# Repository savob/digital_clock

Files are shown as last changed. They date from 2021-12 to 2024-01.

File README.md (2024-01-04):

# Digital Clock
A hardware only digital clock project, my first embedded project without a single microcontroller involved!

Designed in a modular system to allow easy reconfiguration and expirimentation with each module. There are three modules:
1. Display module - These each carry a pair of LED seven segment character displays, their drivers, and a counter for each digit
2. Reset logic module - These recieve the data for a pair of digits and routes it through logic gates to determine if a digit needs to be reset (e.g. at 10)
3. Signal generator module - This generates the base 1 Hz signal used by the clock and provides the power for all other modules

### Small Notice
In the original designs of the reset modules I either forgot or naively didn't bother to include decoupling capacitors for the ICs. This caused the system to be incredibly suseptible to any sort of electrostatic discharge in the surrendings and throwing off the time.

This has been addressed in the newer version.

## Display Module
The main modules present; serve to house and drive two displays each as well as the counter for each digit. The digits are all standard LED seven-segment character displays and can be either common anode (CA) or common cathode (CC) types. The board can accomadate either by switching the driver chip used and a solder jumper accordingly. The left digit is referred to as the "primary" and the right one as "secondary".

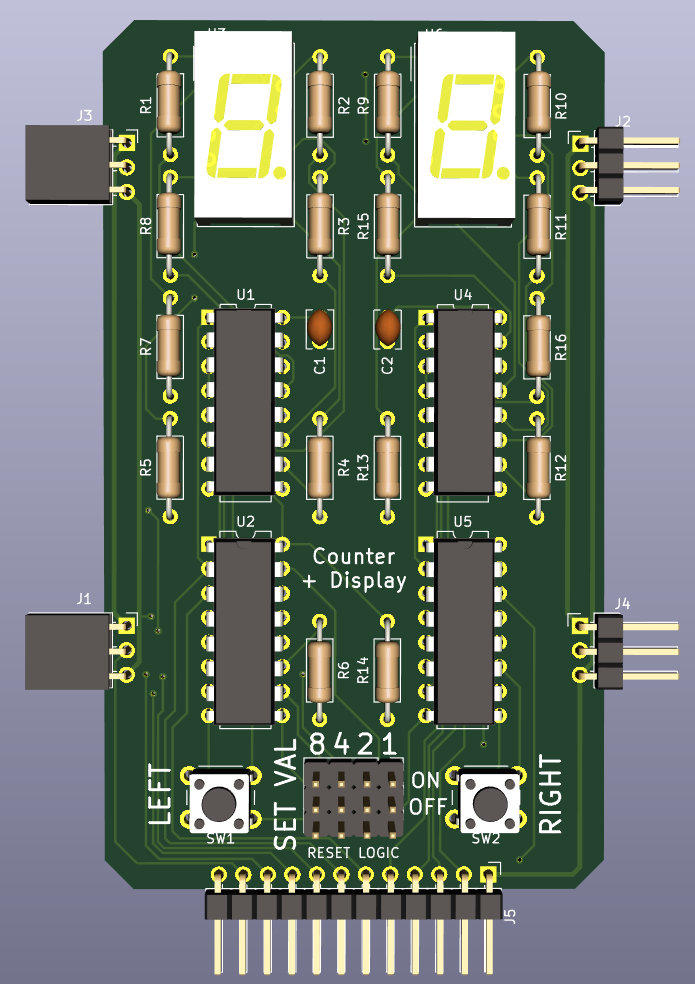
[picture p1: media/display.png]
3D render of the display board


The counters serve to store the value for each digit and increment it when they recieve a clock signal. When a digit "turns over" (returns to zero, resets) this is also used as the signal to increment the next digit up. The result is the count (time) is propagated right to left through the system like a normal clock. The logic to reset digits is not housed on these boards themselves, instead the signals for the value of each couter and their reset signal are routed to the bottom to be handled by the logic modules. 

## Reset Logic Module
This is responsible for "turning over" digits as needed when they reach their upper limit, 6 or 10 (with special cases for the hour digits). These have a set of four two-input AND and OR gates that are to be wired up by the user depending on the behavior desired for a given digit.

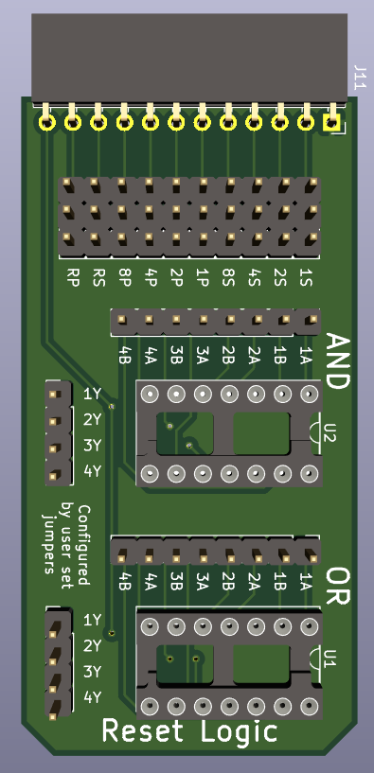
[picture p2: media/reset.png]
3D render of the logic board


For example the ones digit for seconds needs to be reset everytime it reaches ten (10). To arrange for this the user would wire the 8 and 2 signal for that digit (8S and 2S respectively since it would be the secondary digit on that diplay) to the inputs of one of the AND gates available, then connect the output of that AND to the reset for that digit (RS). Now when it is 10 (8 + 2), the reset will be driven high and the counter will return to zero (and increment the next digit up).

## Signal Generator Module
This module serves two purposes: primarily to generate the required 1 Hz base clock for the clock, and secondarily to supply the system with the 5V required via a standard USB.

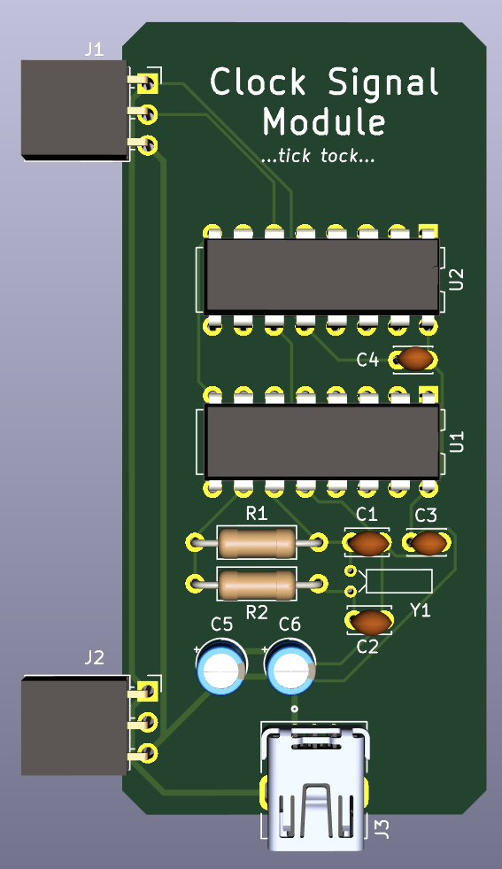
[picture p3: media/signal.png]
3D render of the signal board


The 1 Hz signal is generated using a CD4060 chip driving a 32.768 kHz crystal and dividing down the signal by a factor of 256 to 128 Hz, which is fed into another CD4060 and divided down further by a factor of 128 to produce a steady 1 Hz that is fed into the clock.

### Software Used
KiCad EDA 6.0.1 was originally used to design all the schematics and boards. It has since been updated to KiCad 7.0.10.

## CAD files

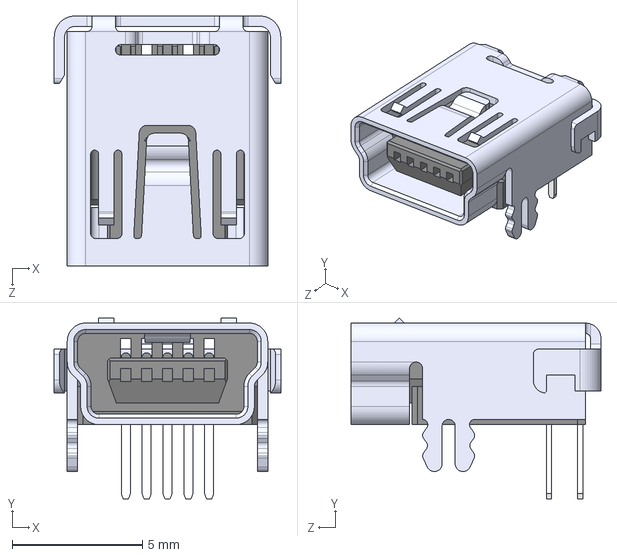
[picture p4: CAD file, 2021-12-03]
signal_generator/2172034-1/2172034-1--3DModel-STEP-56544.STEP
8.70 x 6.94 x 9.60 mm

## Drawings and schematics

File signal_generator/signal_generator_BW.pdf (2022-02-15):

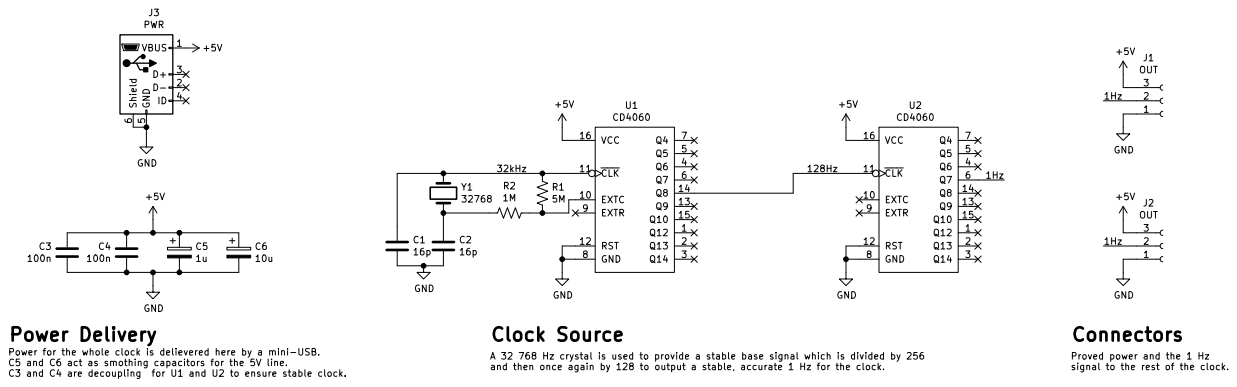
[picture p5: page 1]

A 32 768 Hz crystal is used to provide a stable base signal which is divided by 256
and then once again by 128 to output a stable, accurate 1 Hz for the clock.

Proved power and the 1 Hz
signal to the rest of the clock.

C5 and C6 act as smothing capacitors for the 5V line.
C3 and C4 are decoupling for U1 and U2 to ensure stable clock.

Accepts power via USB and produces 1Hz for the clock system

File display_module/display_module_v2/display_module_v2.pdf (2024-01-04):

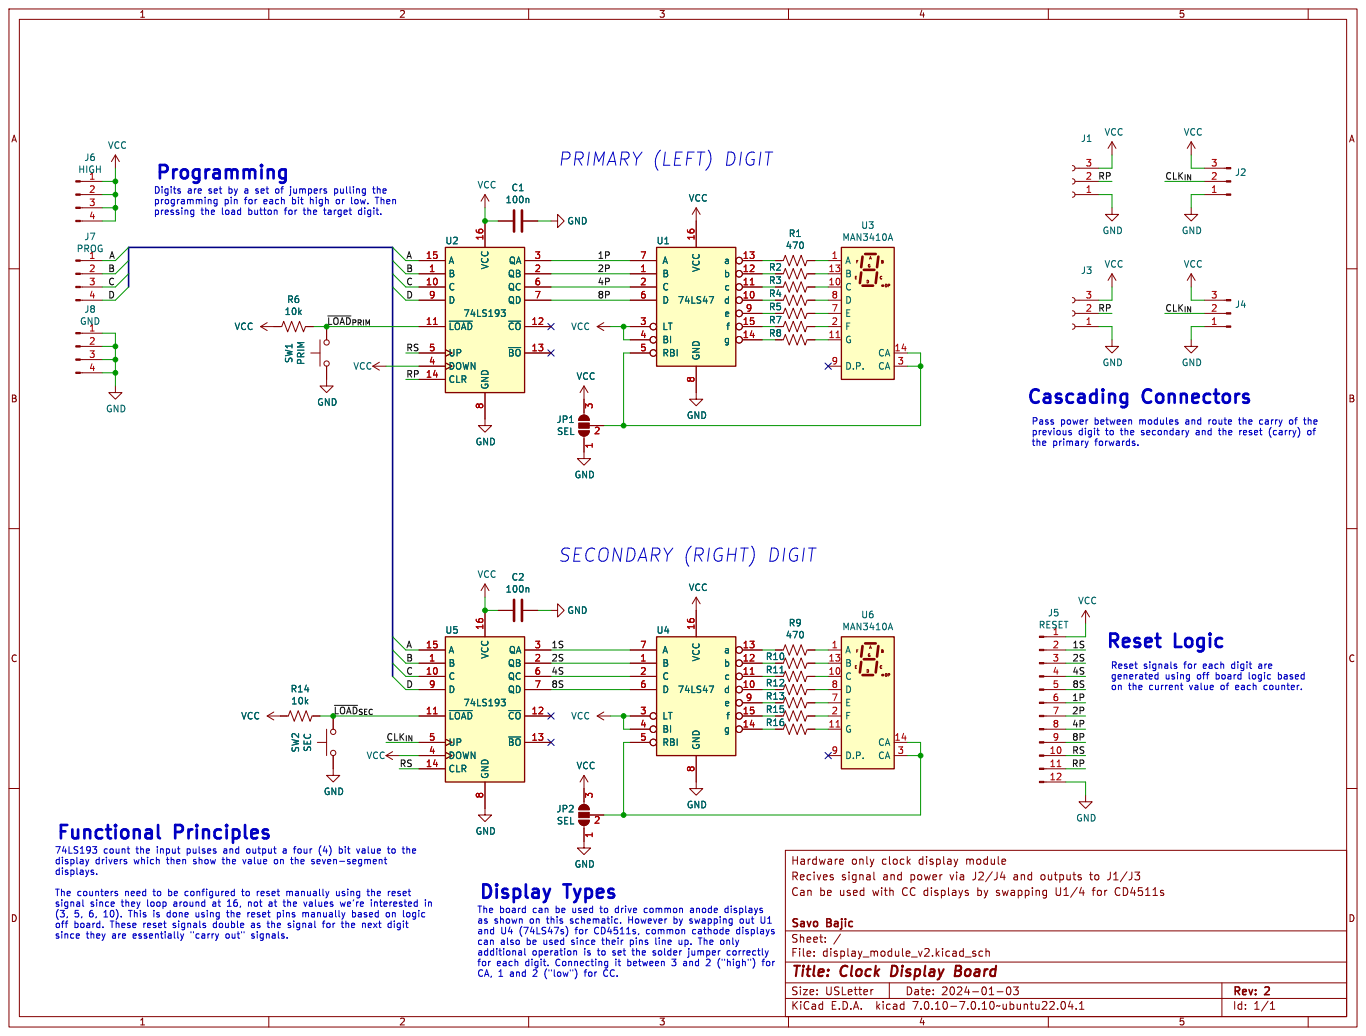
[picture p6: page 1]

VCC
PRIMARY (LEFT) DIGIT Programming

pressing the load button for the target digit.

Pass power between modules and route the carry of the

the primary forwards. 74LS193 count the input pulses and output a four (4) bit value to the

on the current value of each counter.

Id: 1/1 Title: Clock Display Board

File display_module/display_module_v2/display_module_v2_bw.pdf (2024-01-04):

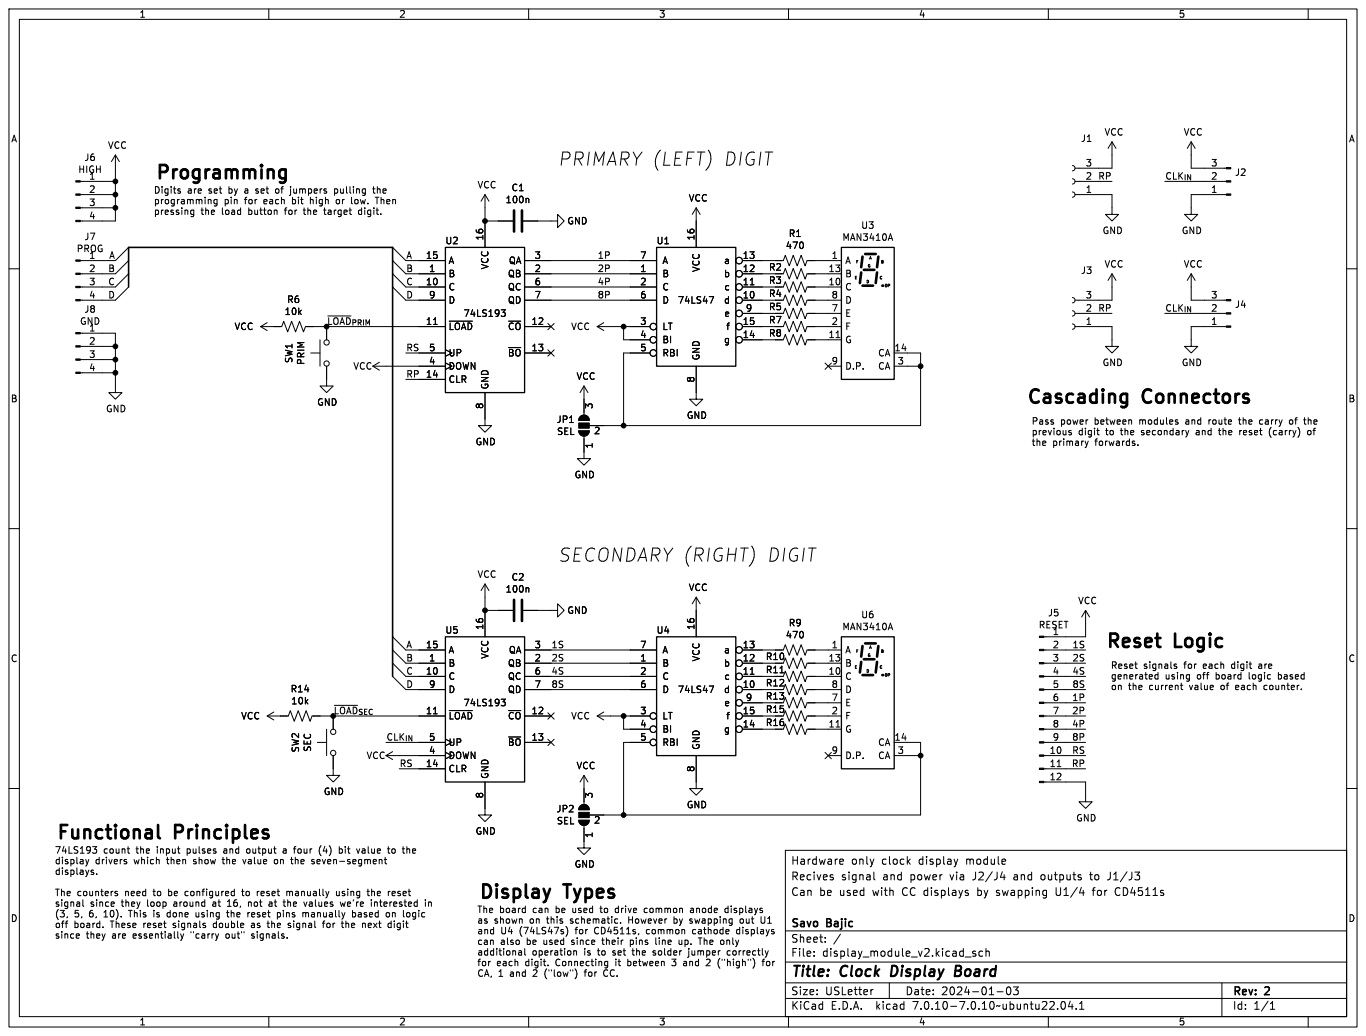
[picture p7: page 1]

Pass power between modules and route the carry of the
the primary forwards. Reset signals for each digit are

74LS193 count the input pulses and output a four (4) bit value to the

Id: 1/1 Title: Clock Display Board

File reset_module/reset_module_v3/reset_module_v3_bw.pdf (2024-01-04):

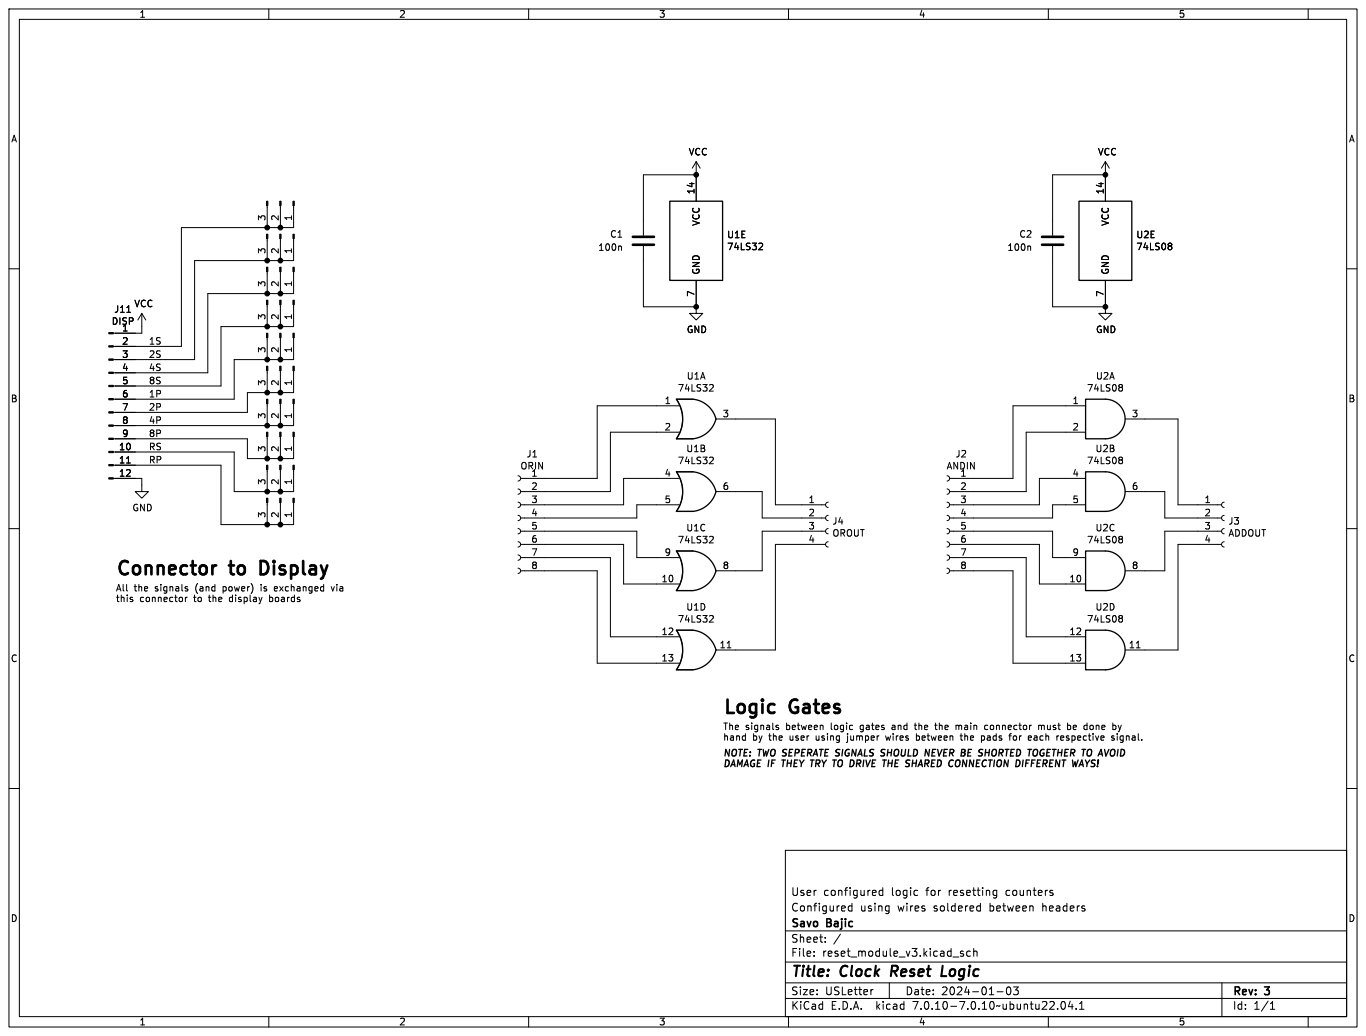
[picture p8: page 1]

DAMAGE IF THEY TRY TO DRIVE THE SHARED CONNECTION DIFFERENT WAYS! Connector to Display

Id: 1/1 Title: Clock Reset Logic

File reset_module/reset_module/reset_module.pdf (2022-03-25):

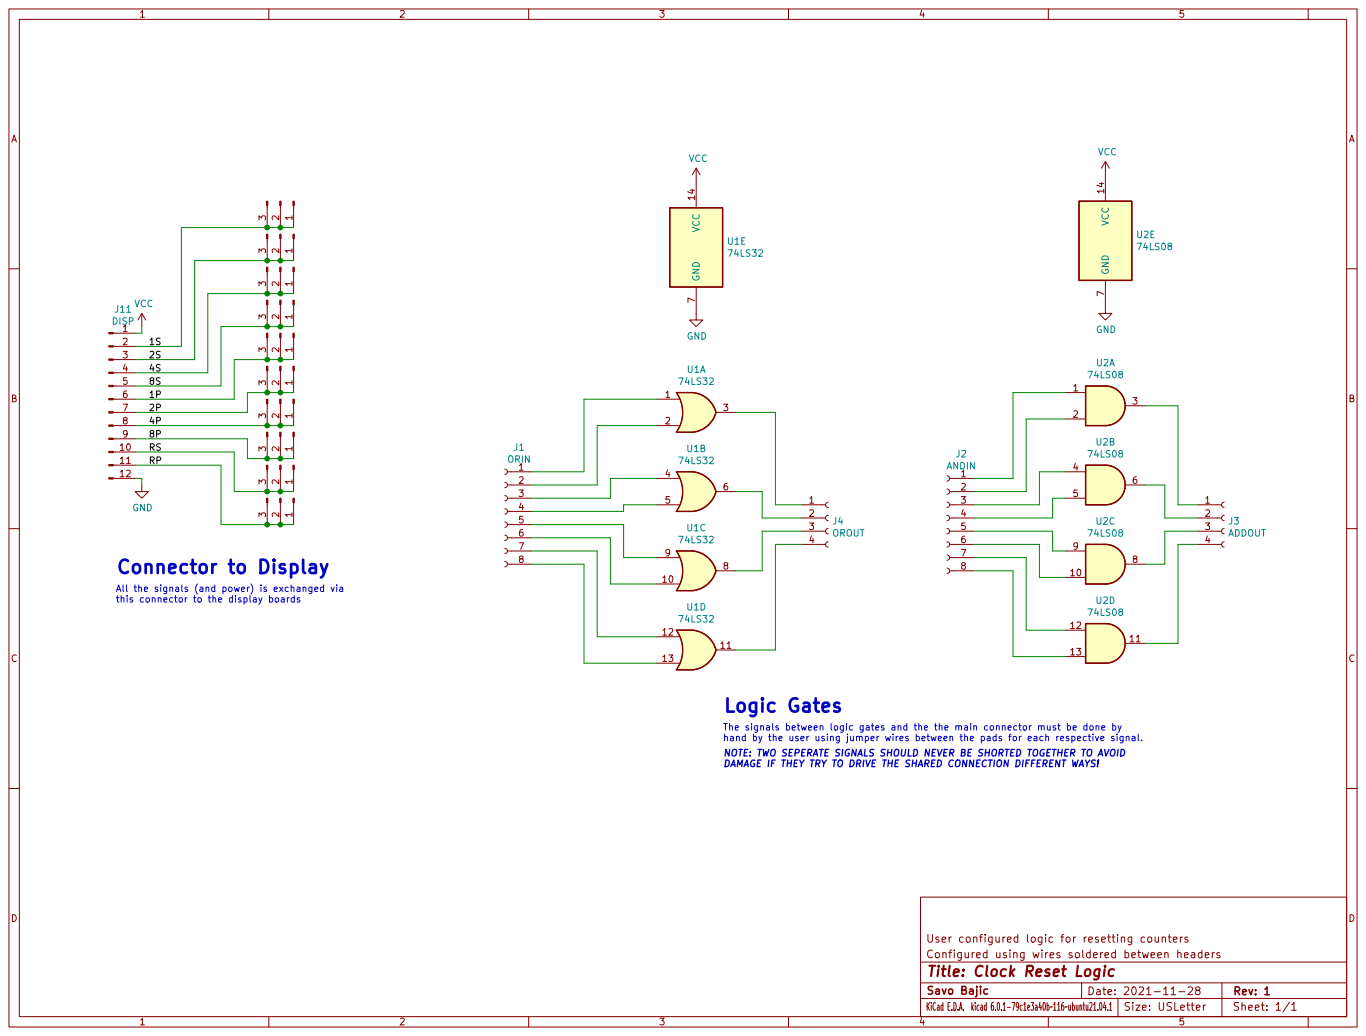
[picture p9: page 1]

All the signals (and power) is exchanged via

DAMAGE IF THEY TRY TO DRIVE THE SHARED CONNECTION DIFFERENT WAYS! Logic Gates

The signals between logic gates and the the main connector must be done by
hand by the user using jumper wires between the pads for each respective signal.

User configured logic for resetting counters KiCad E.D.A. kicad 6.0.1-79c1e3a40b~116~ubuntu21.04.1 | Rev: 1 Size: USLetter Sheet: 1/1 Title: Clock Reset Logic | D Date: 2021-11-28

Configured using wires soldered between headers

Savo Bajic

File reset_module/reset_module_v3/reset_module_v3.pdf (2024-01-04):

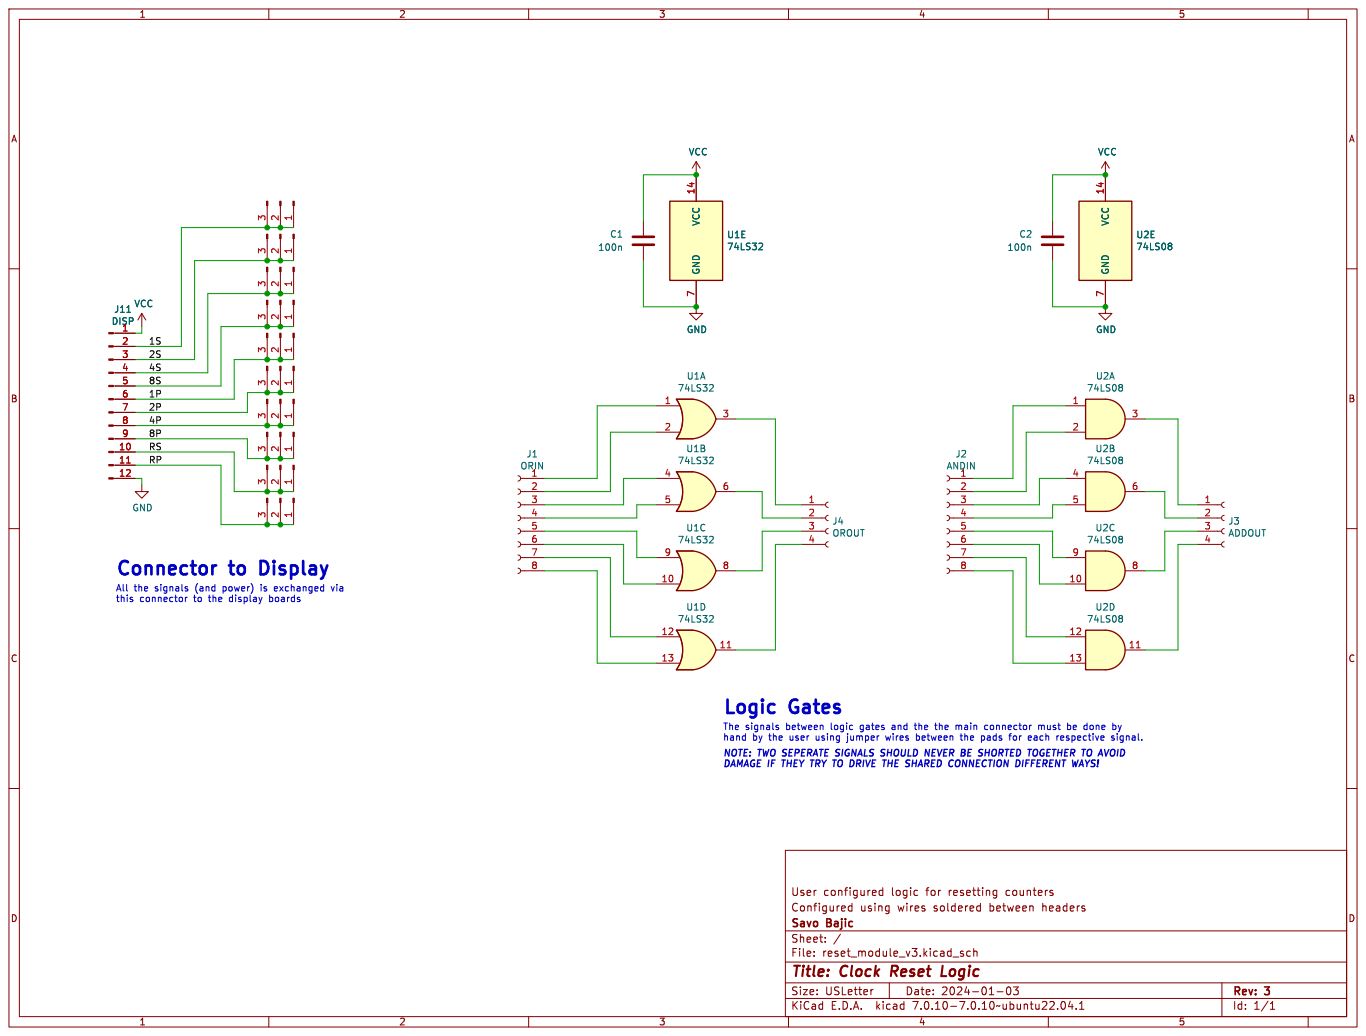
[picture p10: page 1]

NOTE: TWO SEPERATE SIGNALS SHOULD NEVER BE SHORTED TOGETHER TO AVOID
DAMAGE IF THEY TRY TO DRIVE THE SHARED CONNECTION DIFFERENT WAYS!

Id: 1/1 Title: Clock Reset Logic

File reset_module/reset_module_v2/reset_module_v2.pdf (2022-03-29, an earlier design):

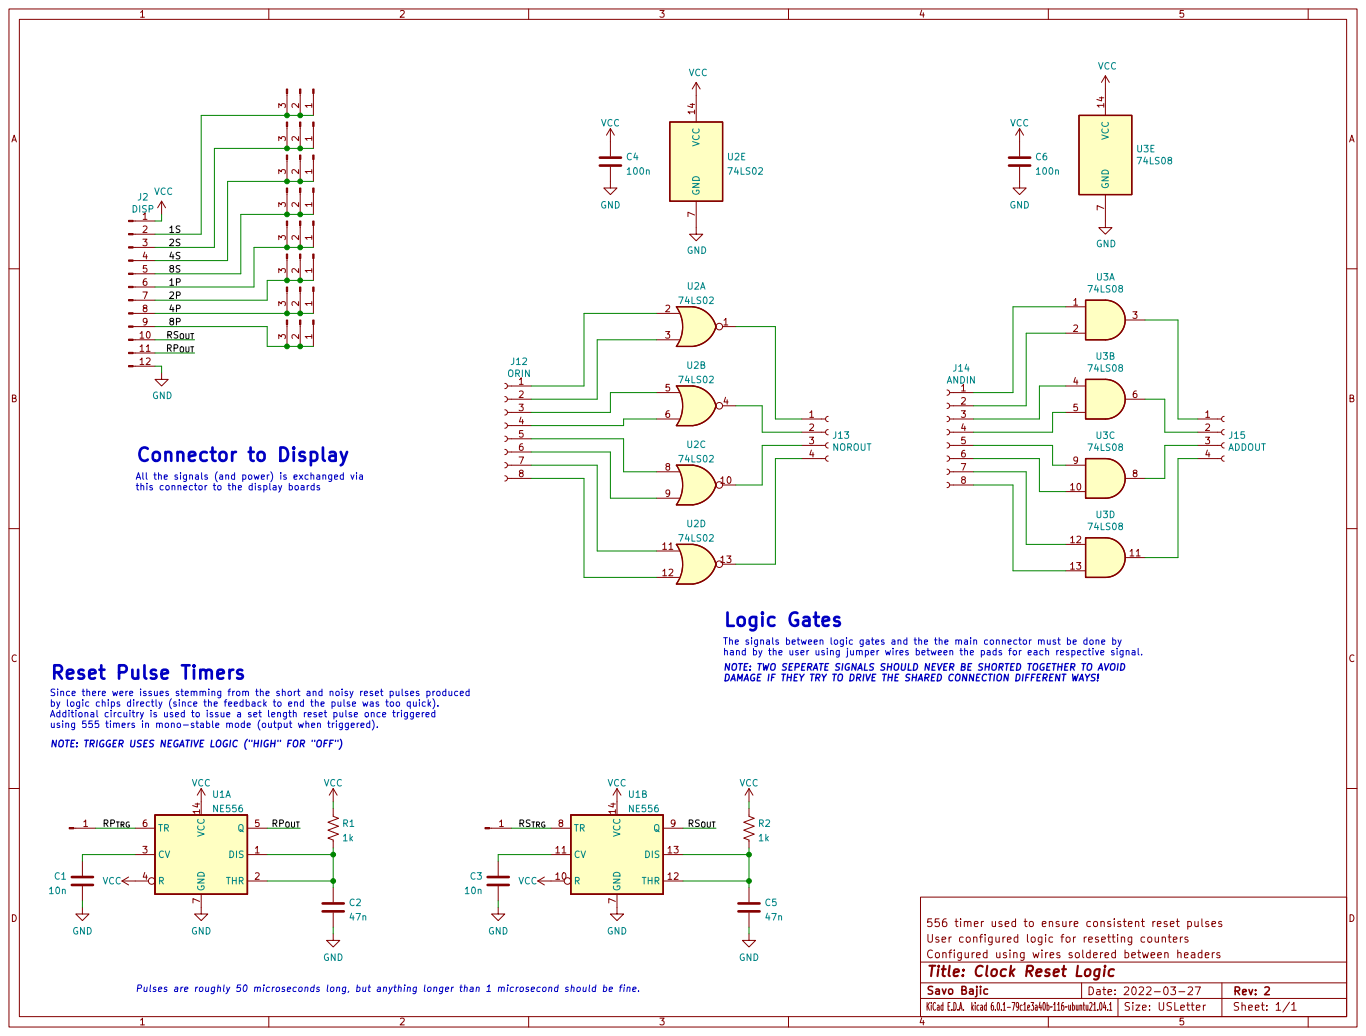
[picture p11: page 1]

DAMAGE IF THEY TRY TO DRIVE THE SHARED CONNECTION DIFFERENT WAYS! Connector to Display

All the signals (and power) is exchanged via
this connector to the display boards

The signals between logic gates and the the main connector must be done by
hand by the user using jumper wires between the pads for each respective signal. NOTE: TWO SEPERATE SIGNALS SHOULD NEVER BE SHORTED TOGETHER TO AVOID

Since there were issues stemming from the short and noisy reset pulses produced
by logic chips directly (since the feedback to end the pulse was too quick).
Additional circuitry is used to issue a set length reset pulse once triggered
using 555 timers in mono-stable mode (output when triggered).
NOTE: TRIGGER USES NEGATIVE LOGIC ("HIGH" FOR "OFF")

556 timer used to ensure consistent reset pulses KiCad E.D.A. kicad 6.0.1-79c1e3a40b~116~ubuntu21.04.1 VCC

User configured logic for resetting counters
Configured using wires soldered between headers

Pulses are roughly 50 microseconds long, but anything longer than 1 microsecond should be fine.

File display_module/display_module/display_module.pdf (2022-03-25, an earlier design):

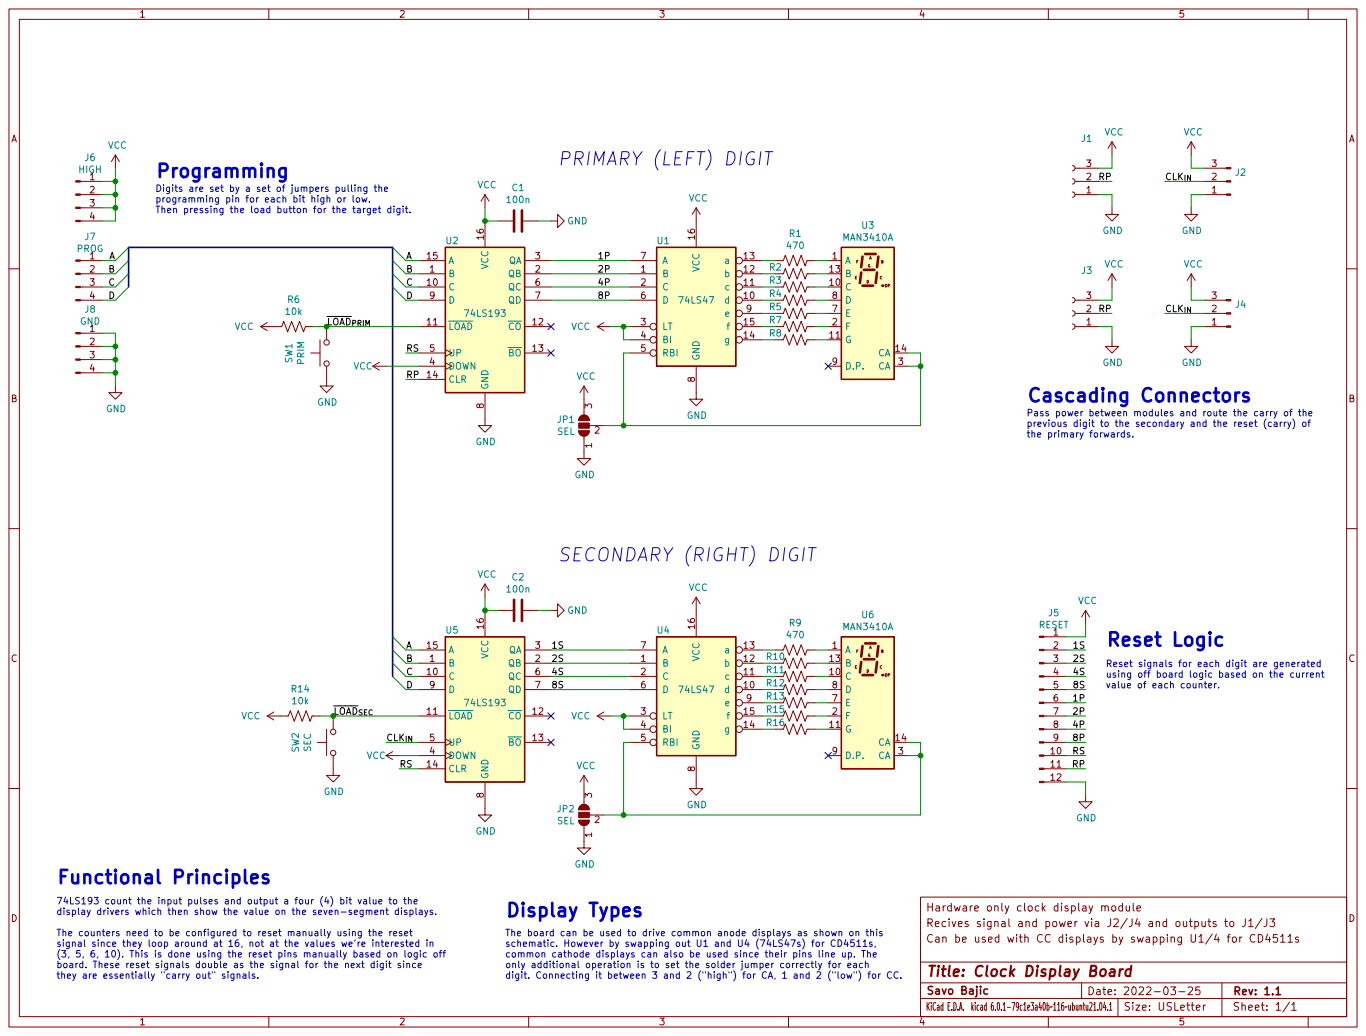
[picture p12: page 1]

Digits are set by a set of jumpers pulling the
programming pin for each bit high or low.
Then pressing the load button for the target digit.

Pass power between modules and route the carry of the
previous digit to the secondary and the reset (carry) of
the primary forwards.

Reset signals for each digit are generated

using off board logic based on the current value of each counter. The board can be used to drive common anode displays as shown on this

74LS193 count the input pulses and output a four (4) bit value to the
display drivers which then show the value on the seven-segment displays.

Recives signal and power via J2/J4 and outputs to J1/J3
Can be used with CC displays by swapping U1/4 for CD4511s

The counters need to be configured to reset manually using the reset
signal since they loop around at 16, not at the values we're interested in
(3, 5, 6, 10). This is done using the reset pins manually based on logic off
board. These reset signals double as the signal for the next digit since
they are essentially "carry out" signals.

schematic. However by swapping out U1 and U4 (74LS47s) for CD4511s,
common cathode displays can also be used since their pins line up. The
only additional operation is to set the solder jumper correctly for each
digit. Connecting it between 3 and 2 ("high") for CA, 1 and 2 ("low") for CC.

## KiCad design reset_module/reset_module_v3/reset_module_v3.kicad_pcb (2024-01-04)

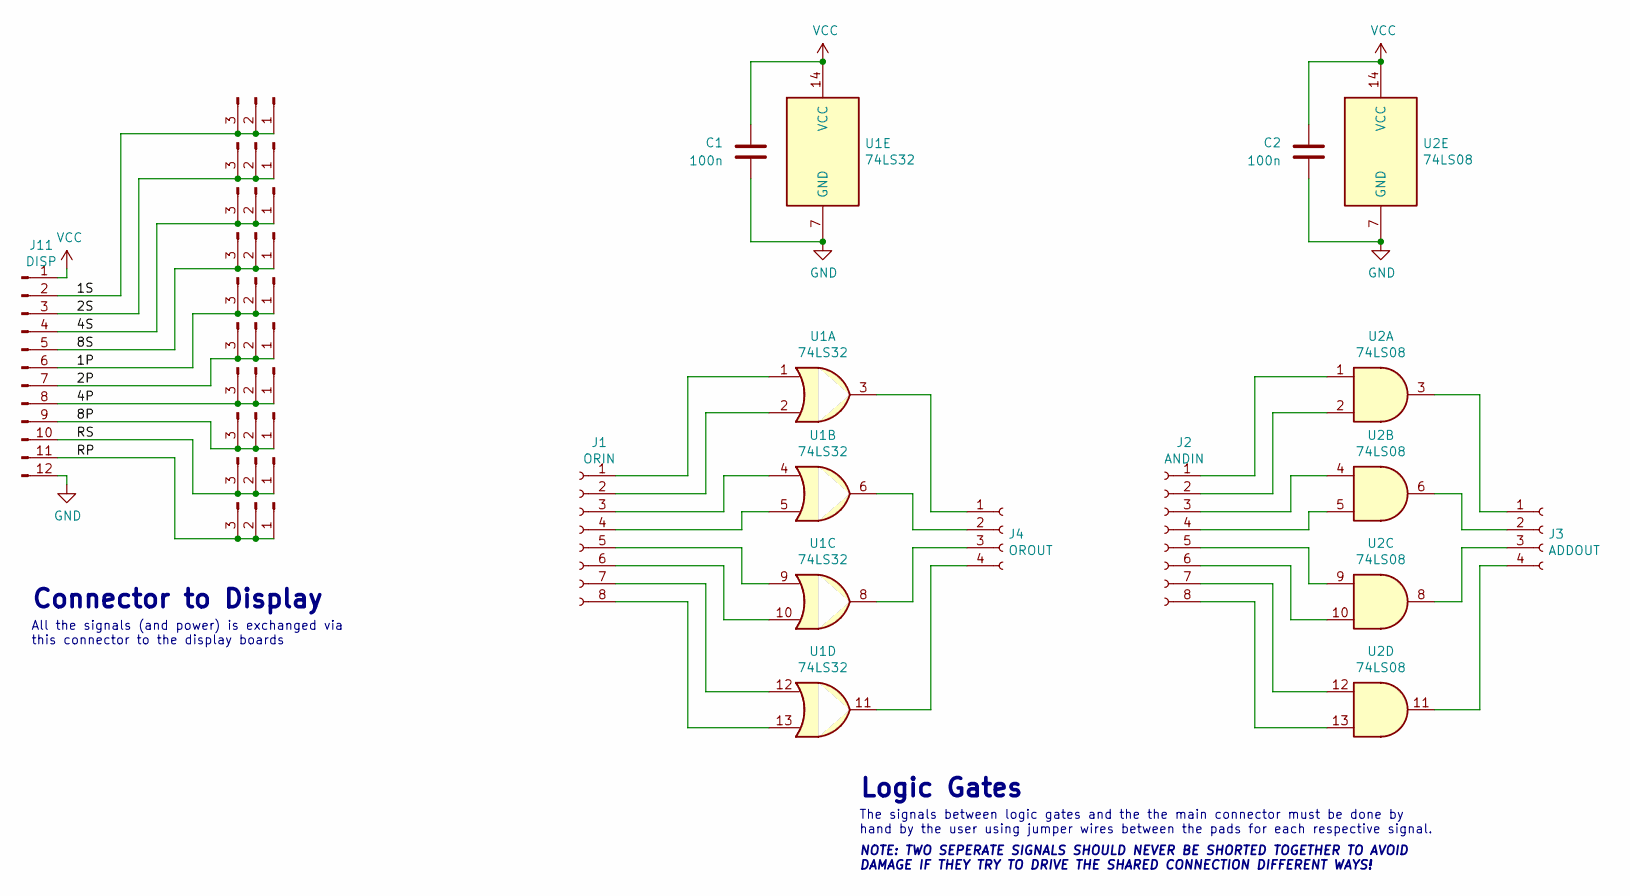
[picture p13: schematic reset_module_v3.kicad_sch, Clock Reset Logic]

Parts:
C1, C2: 100n; C_Disc_D3.8mm_W2.6mm_P2.50mm
J1: ORIN; PinHeader_1x08_P2.54mm_Vertical
J2: ANDIN; PinHeader_1x08_P2.54mm_Vertical
J3: ADDOUT; PinHeader_1x04_P2.54mm_Vertical
J4: OROUT; PinHeader_1x04_P2.54mm_Vertical
J5, J6, J7, J8, J9, J10, J12, J13, J14, J15: Conn_01x03_Male; PinHeader_1x03_P2.54mm_Vertical
J11: DISP; PinSocket_1x12_P2.54mm_Horizontal
U1: 74LS32; DIP-14_W7.62mm_Socket
U2: 74LS08; DIP-14_W7.62mm_Socket

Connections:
/1P: J9.1, J9.2, J9.3, J11.6
/1S: J5.1, J5.2, J5.3, J11.2
/2P: J10.1, J10.2, J10.3, J11.7
/2S: J6.1, J6.2, J6.3, J11.3
/4P: J11.8, J12.1, J12.2, J12.3
/4S: J7.1, J7.2, J7.3, J11.4
/8P: J11.9, J13.1, J13.2, J13.3
/8S: J8.1, J8.2, J8.3, J11.5
/RP: J11.11, J15.1, J15.2, J15.3
/RS: J11.10, J14.1, J14.2, J14.3
GND: C1.2, C2.2, J11.12, U1.7 (GND), U2.7 (GND)
unnamed: J1.1, U1.1
unnamed: J1.2, U1.2
unnamed: J1.3, U1.4
unnamed: J1.4, U1.5
unnamed: J1.5, U1.9
unnamed: J1.6, U1.10
unnamed: J1.7, U1.12
unnamed: J1.8, U1.13
unnamed: J2.1, U2.1
unnamed: J2.2, U2.2
unnamed: J2.3, U2.4
unnamed: J2.4, U2.5
unnamed: J2.5, U2.9
unnamed: J2.6, U2.10
unnamed: J2.7, U2.12
unnamed: J2.8, U2.13
unnamed: J3.1, U2.3
unnamed: J3.2, U2.6
unnamed: J3.3, U2.8
unnamed: J3.4, U2.11
unnamed: J4.1, U1.3
unnamed: J4.2, U1.6
unnamed: J4.3, U1.8
unnamed: J4.4, U1.11
VCC: C1.1, C2.1, J11.1, U1.14 (VCC), U2.14 (VCC)

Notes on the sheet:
Logic Gates
Connector to Display
NOTE: TWO SEPERATE SIGNALS SHOULD NEVER BE SHORTED TOGETHER TO AVOID DAMAGE IF THEY TRY TO DRIVE THE SHARED CONNECTION DIFFERENT WAYS!
The signals between logic gates and the the main connector must be done by hand by the user using jumper wires between the pads for each respective signal.
All the signals (and power) is exchanged via this connector to the display boards

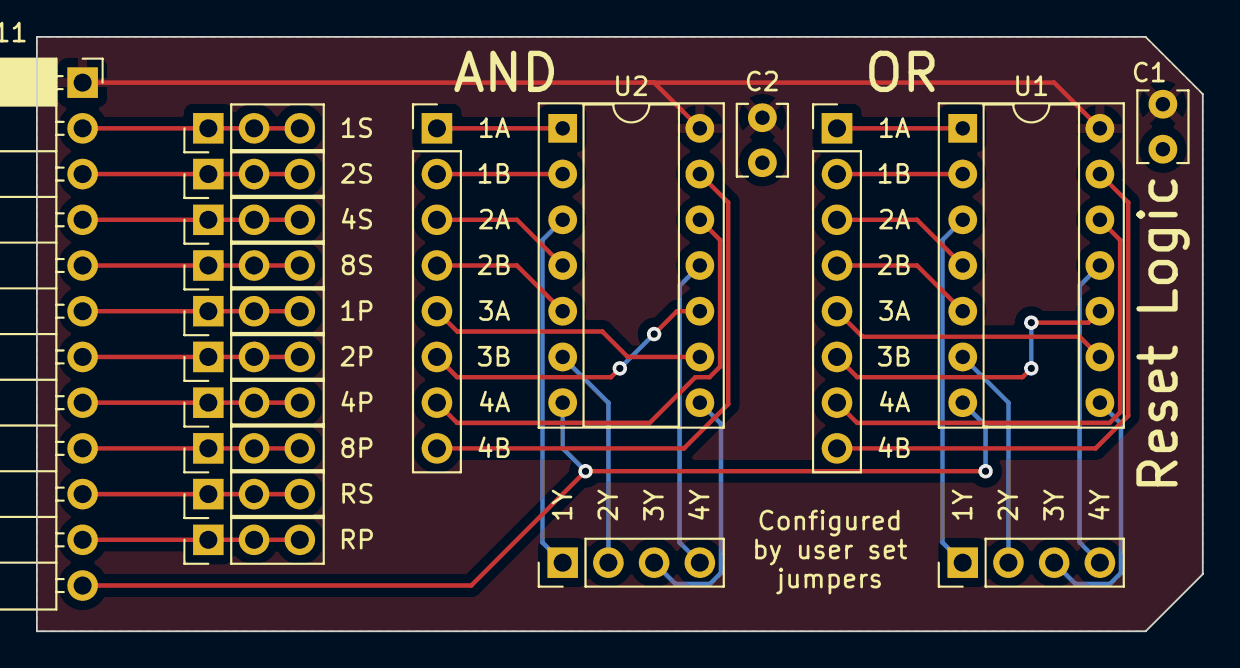
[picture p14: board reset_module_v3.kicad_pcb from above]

Board: 2 copper layers, 64.8 x 33.0 mm, 19 parts (0 on the bottom side), 36 nets.

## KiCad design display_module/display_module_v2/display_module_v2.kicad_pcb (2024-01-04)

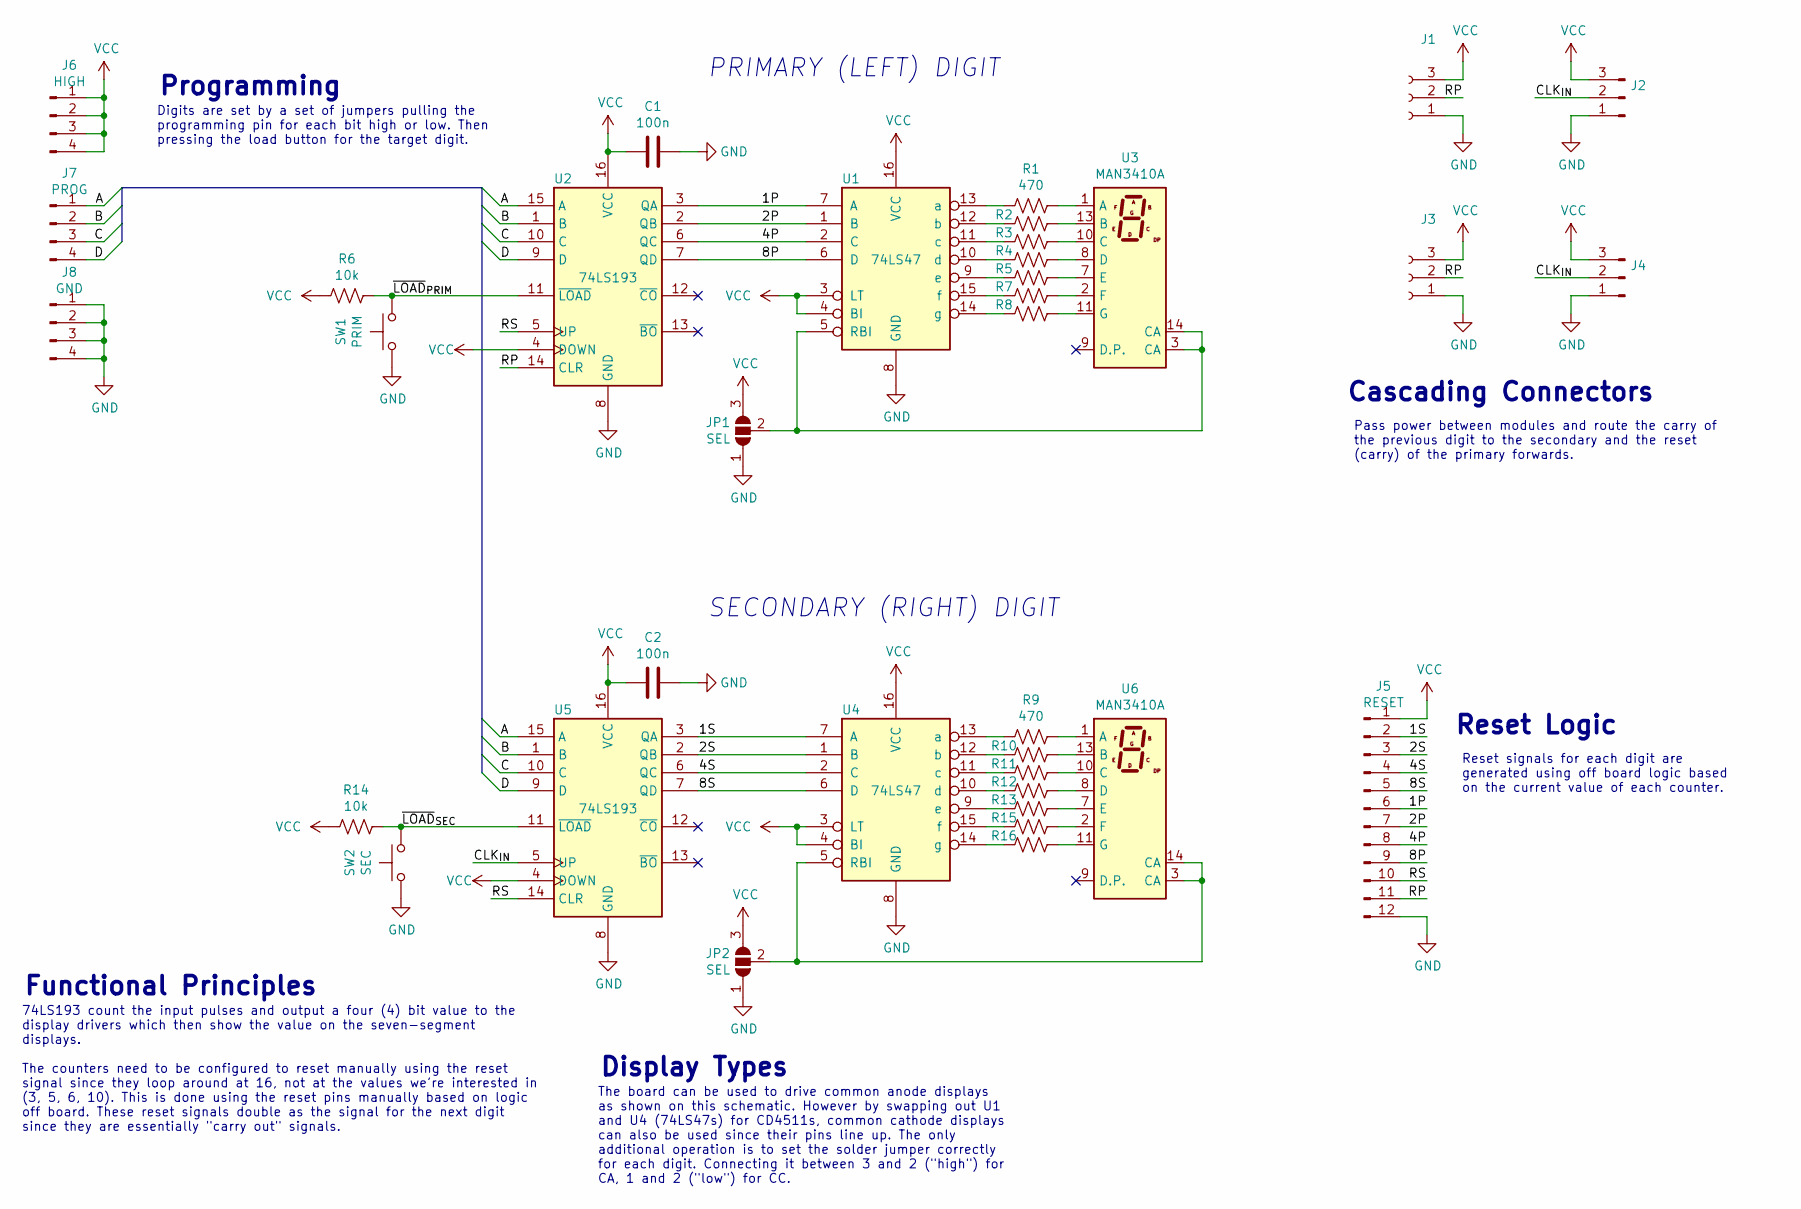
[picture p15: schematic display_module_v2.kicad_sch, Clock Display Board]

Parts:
C1, C2: 100n; C_Disc_D3.8mm_W2.6mm_P2.50mm
J1, J3: Conn_01x03_Female; PinSocket_1x03_P2.54mm_Horizontal
J2, J4: Conn_01x03_Male; PinHeader_1x03_P2.54mm_Horizontal
J5: RESET; PinHeader_1x12_P2.54mm_Horizontal
J6: HIGH; PinHeader_1x04_P2.54mm_Vertical
J7: PROG; PinHeader_1x04_P2.54mm_Vertical
J8: GND; PinHeader_1x04_P2.54mm_Vertical
JP1, JP2: SEL; SolderJumper-3_P1.3mm_Open_RoundedPad1.0x1.5mm
R1, R2, R3, R4, R5, R7, R8, R9, R10, R11, R12, R13, R15, R16: 470; R_Axial_DIN0207_L6.3mm_D2.5mm_P10.16mm_Horizontal
R6, R14: 10k; R_Axial_DIN0207_L6.3mm_D2.5mm_P10.16mm_Horizontal
SW1: PRIM; SW_PUSH_6mm_H4.3mm
SW2: SEC; SW_PUSH_6mm_H4.3mm
U1, U4: 74LS47; DIP-16_W7.62mm
U2, U5: 74LS193; DIP-16_W7.62mm
U3, U6: MAN3410A

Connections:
/1P: J5.6, U1.7 (A), U2.3 (QA)
/1S: J5.2, U4.7 (A), U5.3 (QA)
/2P: J5.7, U1.1 (B), U2.2 (QB)
/2S: J5.3, U4.1 (B), U5.2 (QB)
/4P: J5.8, U1.2 (C), U2.6 (QC)
/4S: J5.4, U4.2 (C), U5.6 (QC)
/8P: J5.9, U1.6 (D), U2.7 (QD)
/8S: J5.5, U4.6 (D), U5.7 (QD)
/A: J7.1, U2.15 (A), U5.15 (A)
/B: J7.2, U2.1 (B), U5.1 (B)
/C: J7.3, U2.10 (C), U5.10 (C)
/CLK_{IN}: J2.2, J4.2, U5.5 (UP)
/D: J7.4, U2.9 (D), U5.9 (D)
/RP: J1.2, J3.2, J5.11, U2.14 (CLR)
/RS: J5.10, U2.5 (UP), U5.14 (CLR)
/~LOAD_{PRIM}: R6.1, SW1.2, U2.11 (~LOAD)
/~LOAD_{SEC}: R14.1, SW2.2, U5.11 (~LOAD)
GND: C1.2, C2.2, J1.1, J2.1, J3.1, J4.1, J5.12, J8.1, J8.2, J8.3, J8.4, JP1.1 (A), JP2.1 (A), SW1.1, SW2.1, U1.8 (GND), U2.8 (GND), U4.8 (GND), U5.8 (GND)
unnamed: JP1.2 (C), U1.5 (RBI), U3.3 (CA), U3.14 (CA)
unnamed: JP2.2 (C), U4.5 (RBI), U6.3 (CA), U6.14 (CA)
unnamed: R1.1, U3.1 (A)
unnamed: R1.2, U1.13 (a)
unnamed: R2.1, U3.13 (B)
unnamed: R2.2, U1.12 (b)
unnamed: R3.1, U3.10 (C)
unnamed: R3.2, U1.11 (c)
unnamed: R4.1, U3.8 (D)
unnamed: R4.2, U1.10 (d)
unnamed: R5.1, U3.7 (E)
unnamed: R5.2, U1.9 (e)
unnamed: R7.1, U3.2 (F)
unnamed: R7.2, U1.15 (f)
unnamed: R8.1, U3.11 (G)
unnamed: R8.2, U1.14 (g)
unnamed: R9.1, U6.1 (A)
unnamed: R9.2, U4.13 (a)
unnamed: R10.1, U6.13 (B)
unnamed: R10.2, U4.12 (b)
unnamed: R11.1, U6.10 (C)
unnamed: R11.2, U4.11 (c)
unnamed: R12.1, U6.8 (D)
unnamed: R12.2, U4.10 (d)
unnamed: R13.1, U6.7 (E)
unnamed: R13.2, U4.9 (e)
unnamed: R15.1, U6.2 (F)
unnamed: R15.2, U4.15 (f)
unnamed: R16.1, U6.11 (G)
unnamed: R16.2, U4.14 (g)
VCC: C1.1, C2.1, J1.3, J2.3, J3.3, J4.3, J5.1, J6.1, J6.2, J6.3, J6.4, JP1.3 (B), JP2.3 (B), R6.2, R14.2, U1.3 (LT), U1.4 (BI), U1.16 (VCC), U2.4 (DOWN), U2.16 (VCC), U4.3 (LT), U4.4 (BI), U4.16 (VCC), U5.4 (DOWN), U5.16 (VCC)

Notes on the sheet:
Reset signals for each digit are generated using off board logic based on the current value of each counter.
Pass power between modules and route the carry of the previous digit to the secondary and the reset (carry) of the primary forwards.
74LS193 count the input pulses and output a four (4) bit value to the display drivers which then show the value on the seven-segment displays. The counters need to be configured to reset manually using the reset signal since they loop around at 16, not at the values we're interested in (3, 5, 6, 10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
Digits are set by a set of jumpers pulling the programming pin for each bit high or low. Then pressing the load button for the target digit.
The board can be used to drive common anode displays as shown on this schematic. However by swapping out U1 and U4 (74LS47s) for CD4511s, common cathode displays can also be used since their pins line up. The only additional operation is to set the solder jumper correctly for each digit. Connecting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
Functional Principles
Programming
PRIMARY (LEFT) DIGIT
Reset Logic
SECONDARY (RIGHT) DIGIT
Display Types
Cascading Connectors

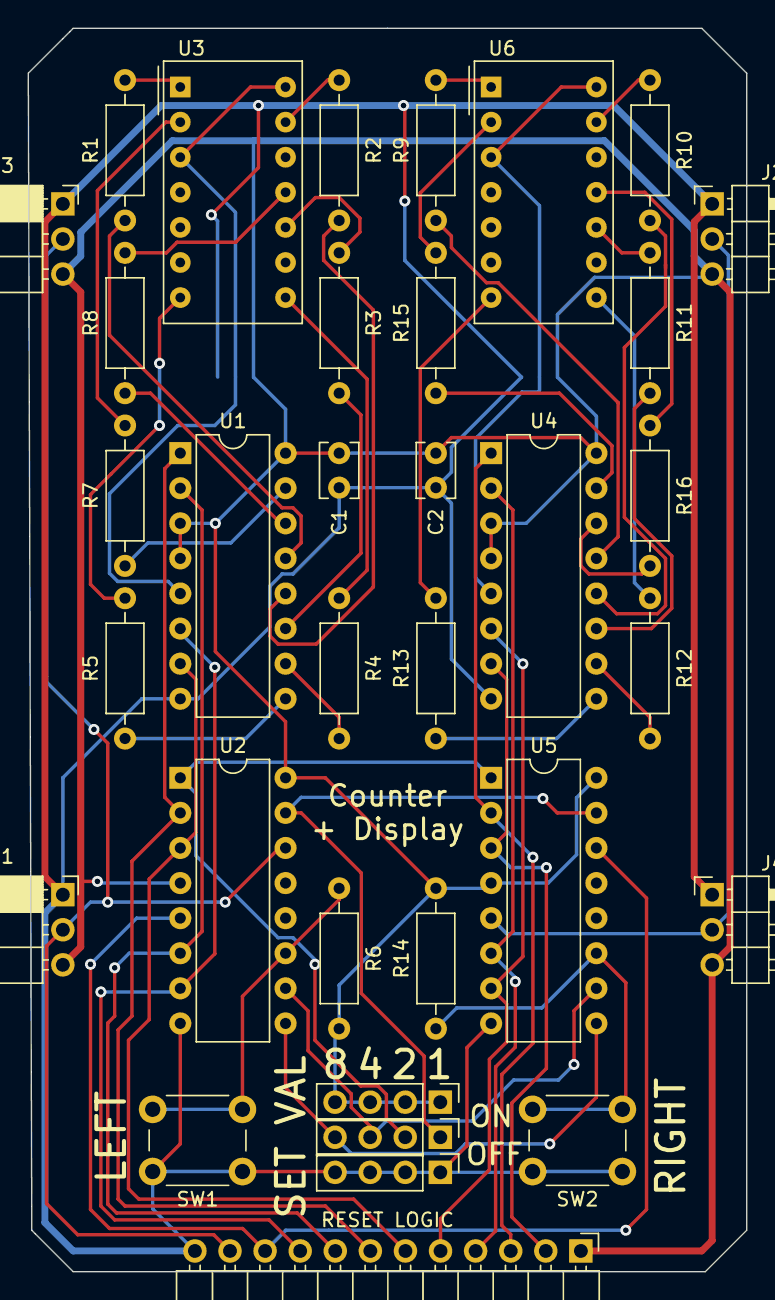
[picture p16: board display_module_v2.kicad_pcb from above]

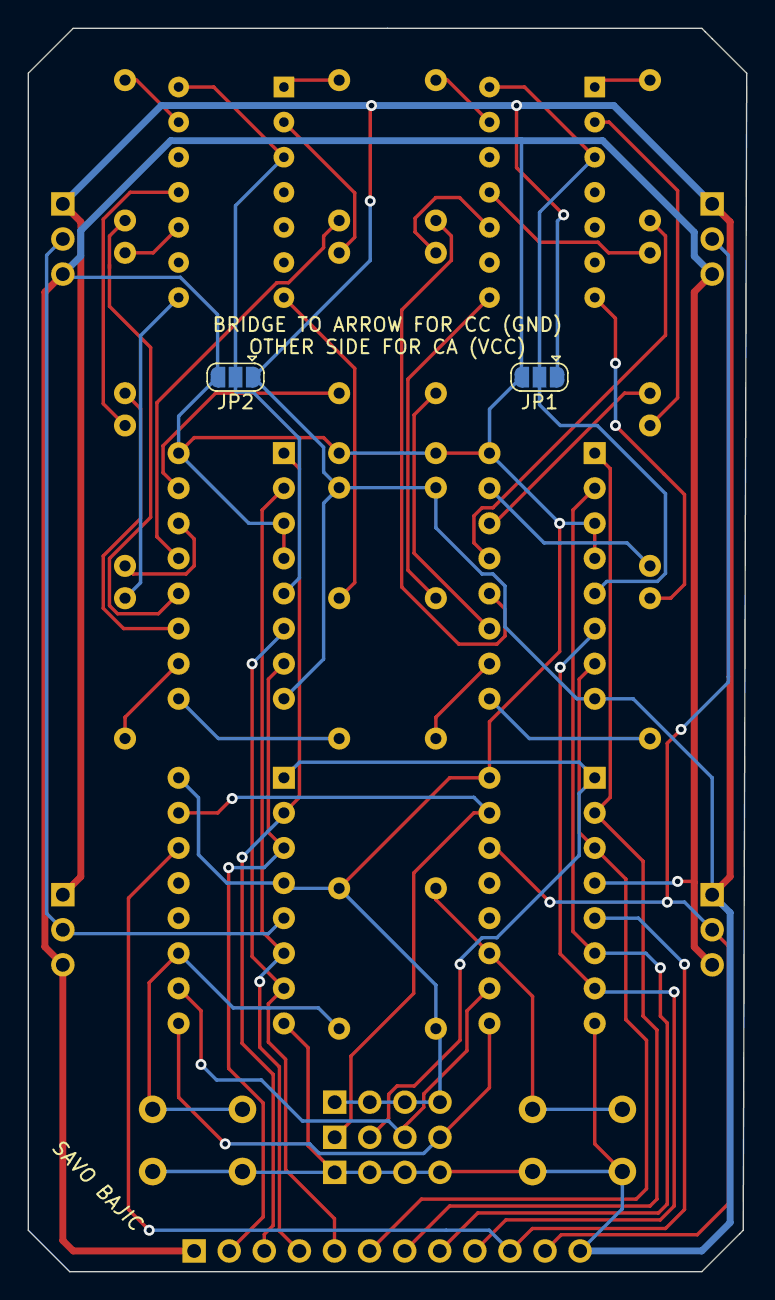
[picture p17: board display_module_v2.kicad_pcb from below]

Board: 2 copper layers, 52.0 x 90.0 mm, 36 parts (2 on the bottom side), 49 nets.

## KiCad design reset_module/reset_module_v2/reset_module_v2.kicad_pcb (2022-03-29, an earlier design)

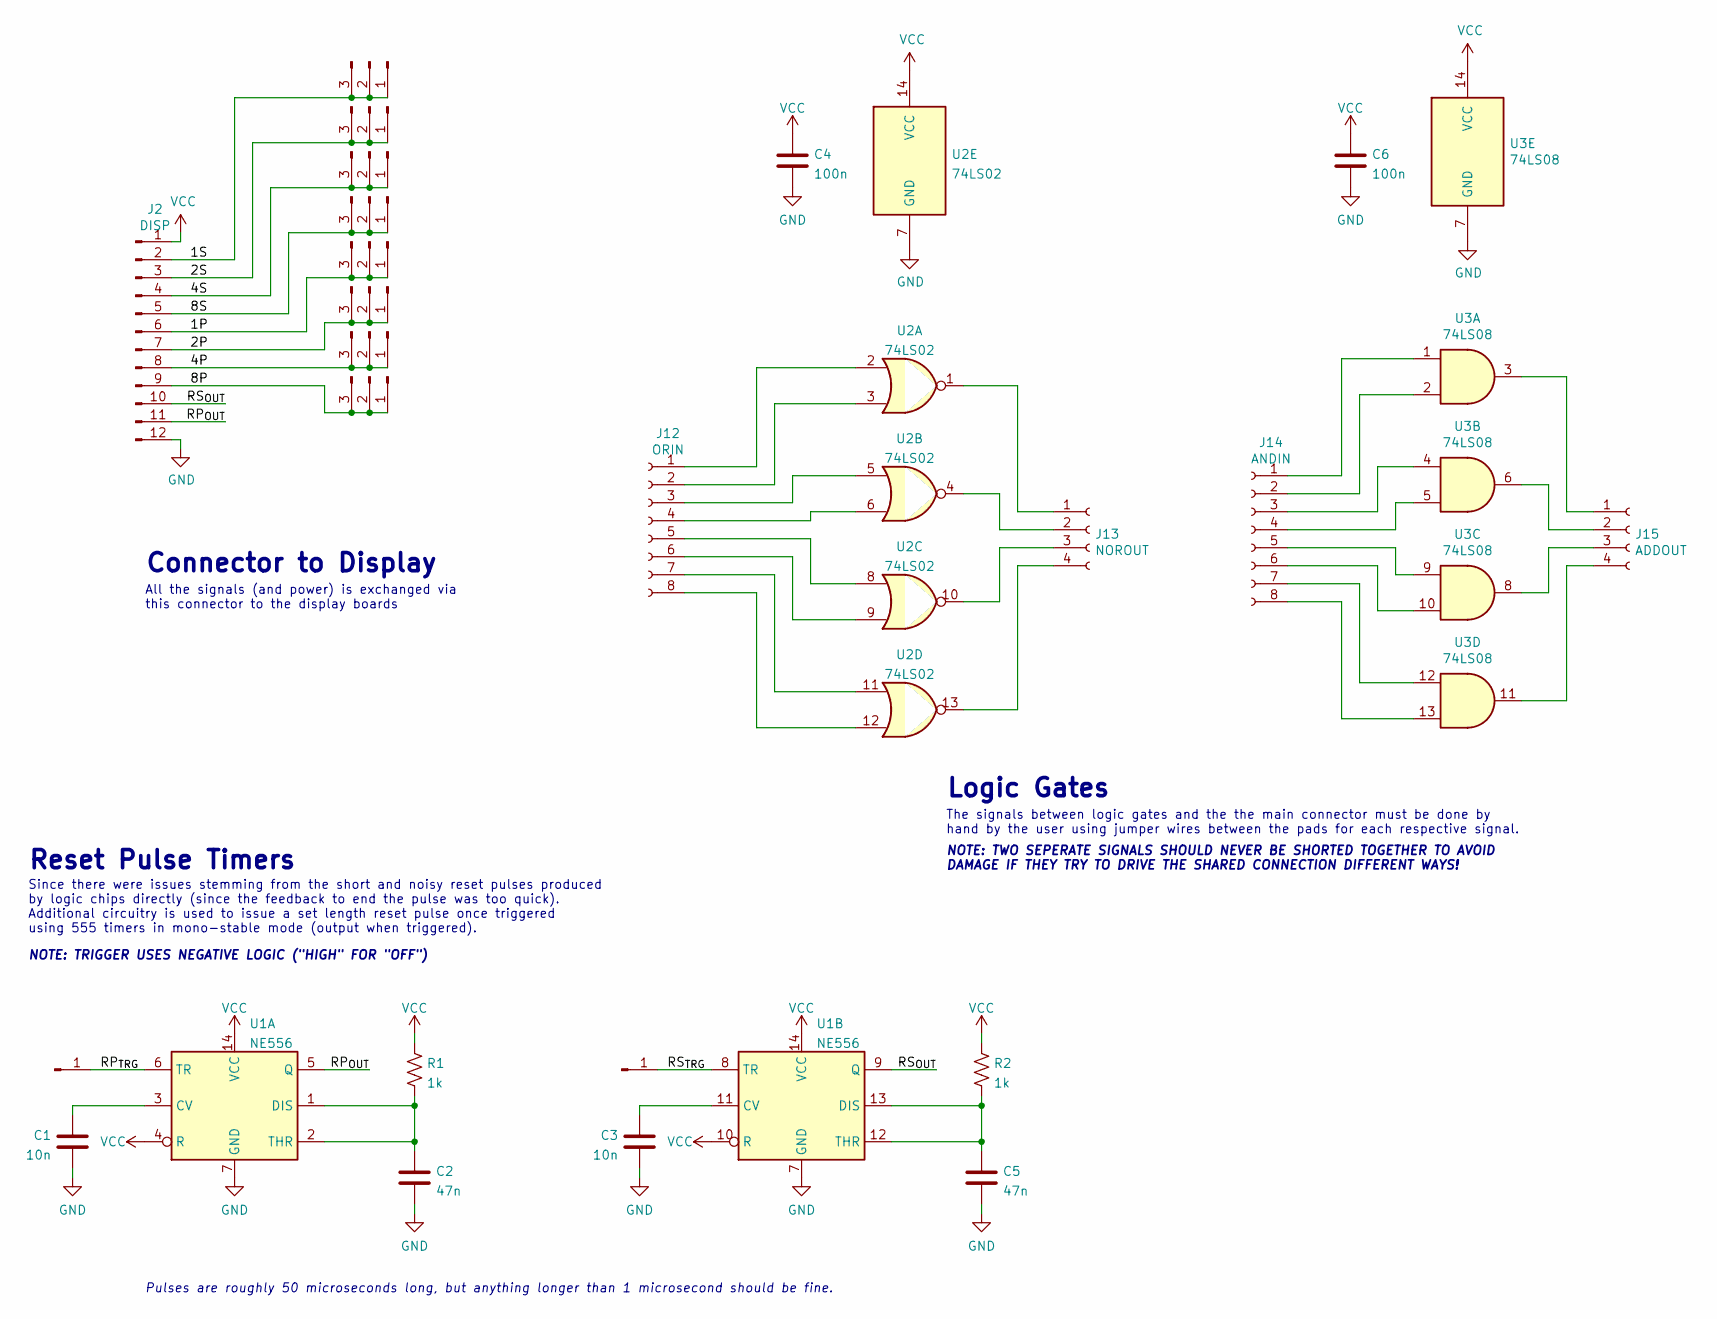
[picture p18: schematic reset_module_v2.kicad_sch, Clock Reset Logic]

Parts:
C1, C3: 10n; C_Disc_D5.0mm_W2.5mm_P2.50mm
C2, C5: 47n; C_Disc_D5.0mm_W2.5mm_P2.50mm
C4, C6: 100n; C_Disc_D5.0mm_W2.5mm_P2.50mm
J1: RP_{TRIGGER}; PinHeader_1x01_P2.54mm_Vertical
J2: DISP; PinSocket_1x12_P2.54mm_Horizontal
J3, J4, J5, J6, J7, J8, J9, J10: Conn_01x03_Male; PinHeader_1x03_P2.54mm_Vertical
J11: RS_{TRIGGER}; PinHeader_1x01_P2.54mm_Vertical
J12: ORIN; PinHeader_1x08_P2.54mm_Vertical
J13: NOROUT; PinHeader_1x04_P2.54mm_Vertical
J14: ANDIN; PinHeader_1x08_P2.54mm_Vertical
J15: ADDOUT; PinHeader_1x04_P2.54mm_Vertical
R1, R2: 1k; R_Axial_DIN0207_L6.3mm_D2.5mm_P10.16mm_Horizontal
U1: NE556; DIP-14_W7.62mm
U2: 74LS02; DIP-14_W7.62mm
U3: 74LS08; DIP-14_W7.62mm

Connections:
/1P: J2.6, J7.1, J7.2, J7.3
/1S: J2.2, J3.1, J3.2, J3.3
/2P: J2.7, J8.1, J8.2, J8.3
/2S: J2.3, J4.1, J4.2, J4.3
/4P: J2.8, J9.1, J9.2, J9.3
/4S: J2.4, J5.1, J5.2, J5.3
/8P: J2.9, J10.1, J10.2, J10.3
/8S: J2.5, J6.1, J6.2, J6.3
/RP_{OUT}: J2.11, U1.5 (Q)
/RP_{TRG}: J1.1, U1.6 (TR)
/RS_{OUT}: J2.10, U1.9 (Q)
/RS_{TRG}: J11.1, U1.8 (TR)
GND: C1.1, C2.2, C3.1, C4.2, C5.2, C6.2, J2.12, U1.7 (GND), U2.7 (GND), U3.7 (GND)
unnamed: C1.2, U1.3 (CV)
unnamed: C2.1, R1.2, U1.1 (DIS), U1.2 (THR)
unnamed: C3.2, U1.11 (CV)
unnamed: C5.1, R2.2, U1.12 (THR), U1.13 (DIS)
unnamed: J12.1, U2.2
unnamed: J12.2, U2.3
unnamed: J12.3, U2.5
unnamed: J12.4, U2.6
unnamed: J12.5, U2.8
unnamed: J12.6, U2.9
unnamed: J12.7, U2.11
unnamed: J12.8, U2.12
unnamed: J13.1, U2.1
unnamed: J13.2, U2.4
unnamed: J13.3, U2.10
unnamed: J13.4, U2.13
unnamed: J14.1, U3.1
unnamed: J14.2, U3.2
unnamed: J14.3, U3.4
unnamed: J14.4, U3.5
unnamed: J14.5, U3.9
unnamed: J14.6, U3.10
unnamed: J14.7, U3.12
unnamed: J14.8, U3.13
unnamed: J15.1, U3.3
unnamed: J15.2, U3.6
unnamed: J15.3, U3.8
unnamed: J15.4, U3.11
VCC: C4.1, C6.1, J2.1, R1.1, R2.1, U1.4 (R), U1.10 (R), U1.14 (VCC), U2.14 (VCC), U3.14 (VCC)

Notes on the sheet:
Since there were issues stemming from the short and noisy reset pulses produced by logic chips directly (since the feedback to end the pulse was too quick). Additional circuitry is used to issue a set length reset pulse once triggered using 555 timers in mono-stable mode (output when triggered).
Logic Gates
Connector to Display
NOTE: TWO SEPERATE SIGNALS SHOULD NEVER BE SHORTED TOGETHER TO AVOID DAMAGE IF THEY TRY TO DRIVE THE SHARED CONNECTION DIFFERENT WAYS!
The signals between logic gates and the the main connector must be done by hand by the user using jumper wires between the pads for each respective signal.
NOTE: TRIGGER USES NEGATIVE LOGIC ("HIGH" FOR "OFF")
Reset Pulse Timers
All the signals (and power) is exchanged via this connector to the display boards
Pulses are roughly 50 microseconds long, but anything longer than 1 microsecond should be fine.

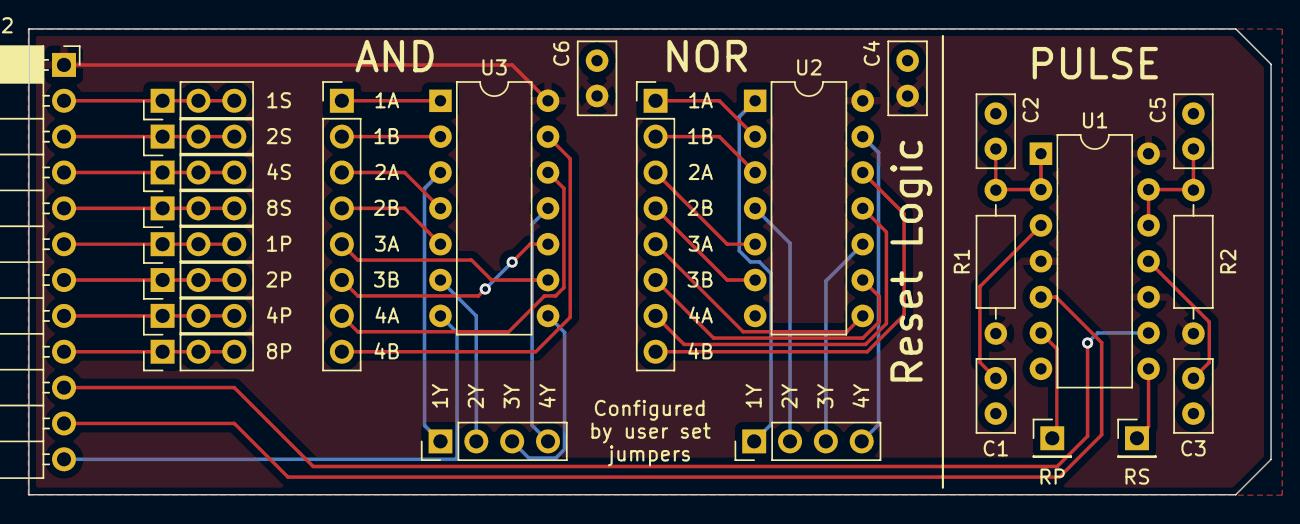
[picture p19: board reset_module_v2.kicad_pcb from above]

Board: 2 copper layers, 88.0 x 33.0 mm, 26 parts (0 on the bottom side), 42 nets.

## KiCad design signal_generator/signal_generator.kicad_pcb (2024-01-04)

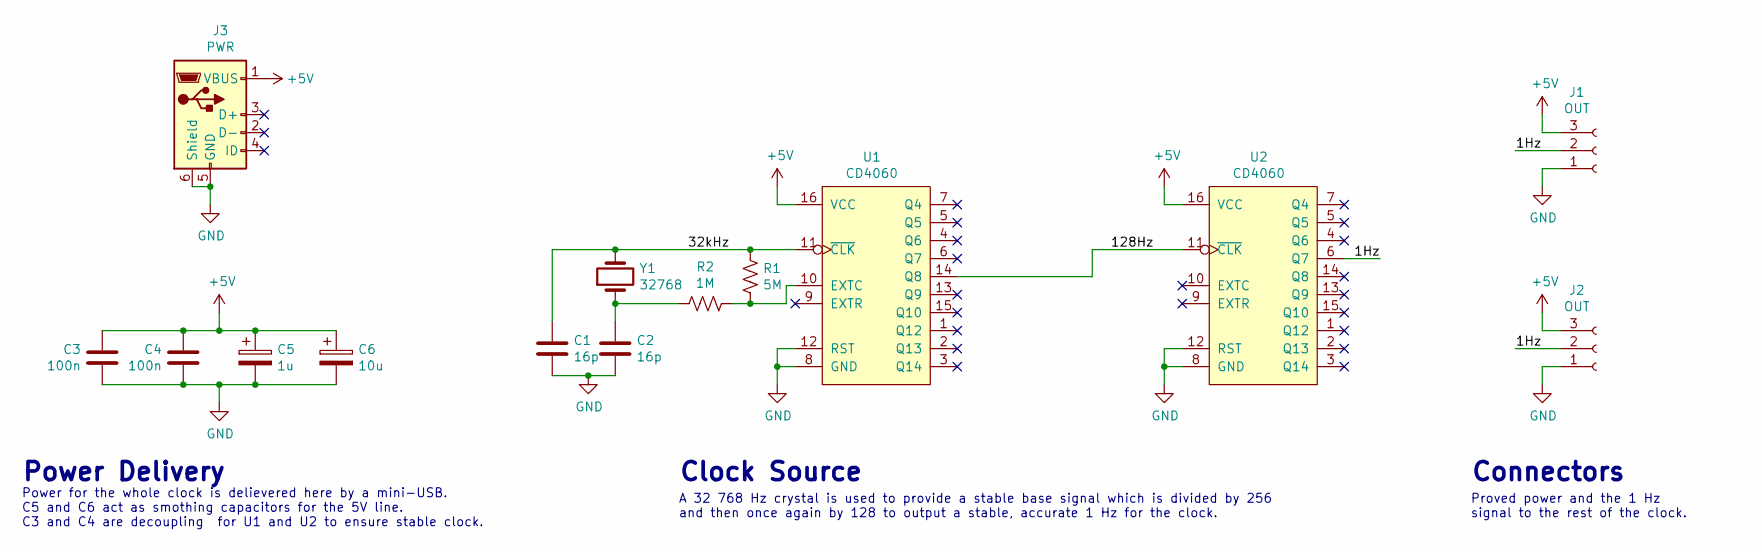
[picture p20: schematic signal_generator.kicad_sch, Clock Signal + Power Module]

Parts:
C1, C2: 16p; C_Disc_D3.4mm_W2.1mm_P2.50mm
C3, C4: 100n; C_Disc_D3.0mm_W2.0mm_P2.50mm
C5: 1u; CP_Radial_D4.0mm_P2.00mm
C6: 10u; CP_Radial_D4.0mm_P2.00mm
J1, J2: OUT; PinSocket_1x03_P2.54mm_Horizontal
J3: PWR; TE_2172034-1
R1: 5M; R_Axial_DIN0207_L6.3mm_D2.5mm_P10.16mm_Horizontal
R2: 1M; R_Axial_DIN0207_L6.3mm_D2.5mm_P10.16mm_Horizontal
U1, U2: CD4060; DIP-16_W7.62mm
Y1: 32768; Crystal_DS15_D1.5mm_L5.0mm_Horizontal

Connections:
+5V: C3.2, C4.2, C5.1, C6.1, J1.3, J2.3, J3.1 (VBUS), U1.16 (VCC), U2.16 (VCC)
/1Hz: J1.2, J2.2, U2.6 (Q7)
/32kHz: C1.1, R1.2, U1.11 (~CLK), Y1.2
/128Hz: U1.14 (Q8), U2.11 (~CLK)
GND: C1.2, C2.2, C3.1, C4.1, C5.2, C6.2, J1.1, J2.1, J3.5 (GND), J3.6 (Shield), U1.8 (GND), U1.12 (RST), U2.8 (GND), U2.12 (RST)
unnamed: C2.1, R2.1, Y1.1
unnamed: R1.1, R2.2, U1.10 (EXTC)

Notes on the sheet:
Power Delivery
Clock Source
Proved power and the 1 Hz signal to the rest of the clock.
A 32 768 Hz crystal is used to provide a stable base signal which is divided by 256 and then once again by 128 to output a stable, accurate 1 Hz for the clock.
Connectors
Power for the whole clock is delievered here by a mini-USB. C5 and C6 act as smothing capacitors for the 5V line. C3 and C4 are decoupling for U1 and U2 to ensure stable clock.

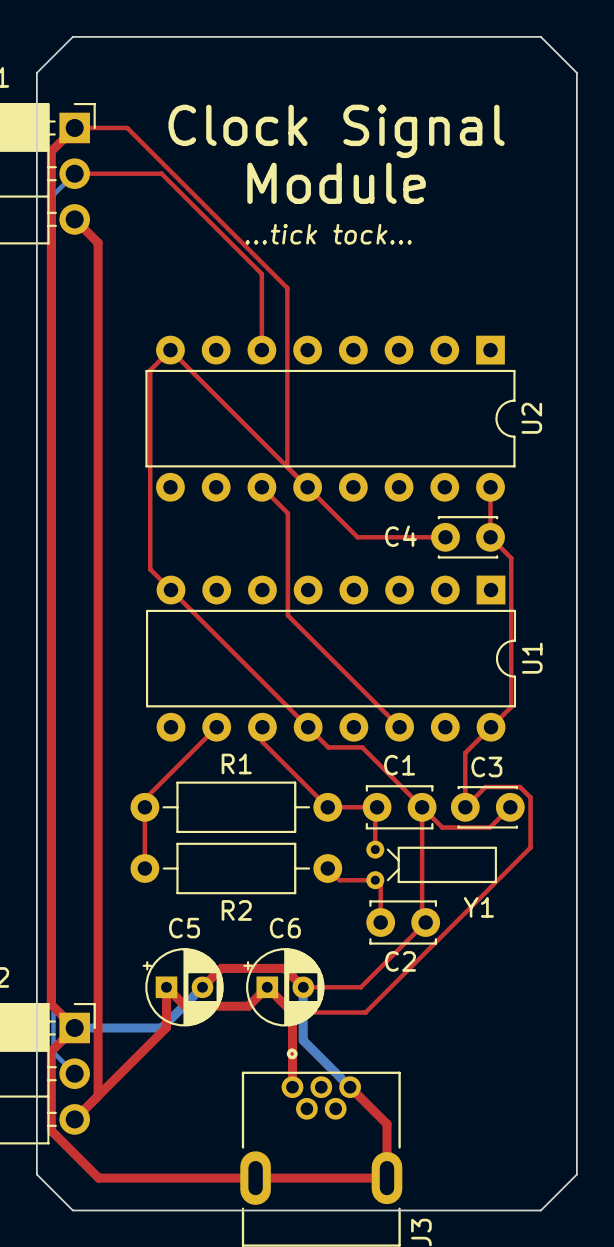
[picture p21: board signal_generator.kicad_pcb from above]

Board: 2 copper layers, 30.0 x 65.2 mm, 14 parts (0 on the bottom side), 7 nets.

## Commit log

2021-12-03 Initial upload of hardware files
    [2172034-1--3DModel-STEP-56544.STEP, display_module.kicad_pcb, display_module.sch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]
2021-12-03 Uploaded renders of each board
2022-02-15 Migrated to KiCad 6
    [display_module.kicad_pcb, display_module.kicad_sch, reset_modules.kicad_pcb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]
2022-02-15 Prepared gerber files for manufacture
    Also added dimensions to board layout files
    [display_module-B_Cu.gbl, display_module-B_Mask.gbs, display_module-B_Paste.gbp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]
2022-03-25 New schematics and minor rev for display
    Added a signal name to the display board for the data load signals for each counter.
    [display_module.kicad_pcb, display_module.kicad_sch]
2022-03-29 Added revised reset module files
    [reset_module_v2.kicad_pcb, reset_module_v2.kicad_sch]
2024-01-04 Added decoupling capacitors to reset module
    [display_module_v2-B_Cu.gbl, display_module_v2-B_Mask.gbs, display_module_v2-B_Paste.gbp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]
